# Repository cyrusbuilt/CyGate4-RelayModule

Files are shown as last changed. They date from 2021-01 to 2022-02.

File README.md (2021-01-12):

# CyGate4-RelayModule

Add-on relay module for CyGate4

## Synopsis

This is a relay add-on module for [CyGate4](https://github.com/cyrusbuilt/CyGate4).  It provides 5 addressable relays capable of switching up to 15A @ 125VAC.  This module connects to CyGate4 using the I2C (aka 2-wire) bus. It can be powered from CyGate4 itself, or from a separate 5VDC supply. Support for this module is built-in to the CyGate4 firmware. Since this relay module is based on the MCP23017, it uses a 7bit address scheme where the first 4 bits are already set and the last 3 bits are configurable via jumpers on J1 - J3. The jumpers *MUST* be set and cannot be left off.

For example, the jumper must connect the center pin and either plus (+) or or minus (-) pins. Positive (high) represents a binary 1 and negative (low) represents a binary 0.  You can have a maximum of 7 relay modules (or any other MCP23017-based devices for that matter) connected to CyGate4 at any given time. Be sure to configure that address so as not to conflict with any other devices. NOTE: Address 0 (0x20) is reserved by CyGate4 itself (all jumpers set to center and minus) and cannot be used by any other devices.

As long as the address is configured properly, the device will be auto-detected during CyGate4's boot cycle and initialized. Once initialized, the relays can be configured via CyGate4's config file or via configure/control messages sent to CyGate4 via MQTT.

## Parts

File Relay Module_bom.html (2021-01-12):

Label | Part Type | Properties
C1 | Ceramic Capacitor | voltage 6.3V; capacitance 100nF; package 100 mil [THT, multilayer]
C2 | Ceramic Capacitor | voltage 6.3V; capacitance 100nF; package 100 mil [THT, multilayer]
D1 | Rectifier Diode | type Rectifier; package 300 mil [THT]; part # 1N4001
IC1 | MCP23017 I2C I/O Expander | variant PDIP
IC2 | ULN2803A | variant ULN2803A; package THT
J1 | Generic male header - 3 pins | pin spacing 0.1in (2.54mm); row single; pins 3; form ♂ (male); package THT; hole size 1.0mm,0.508mm
J2 | Generic male header - 3 pins | pin spacing 0.1in (2.54mm); row single; pins 3; form ♂ (male); package THT; hole size 1.0mm,0.508mm
J3 | Generic male header - 3 pins | pin spacing 0.1in (2.54mm); row single; pins 3; form ♂ (male); package THT; hole size 1.0mm,0.508mm
J4 | Screw terminal - 4 pins | pin spacing 0.137in (3.5mm); pins 4; package THT; hole size 1.0mm,0.508mm
J5 | Screw terminal - 3 pins | pin spacing 0.137in (3.5mm); pins 3; package THT; hole size 1.0mm,0.508mm
J6 | Screw terminal - 3 pins | pin spacing 0.137in (3.5mm); pins 3; package THT; hole size 1.0mm,0.508mm
J7 | Screw terminal - 3 pins | pin spacing 0.137in (3.5mm); pins 3; package THT; hole size 1.0mm,0.508mm
J8 | Screw terminal - 3 pins | pin spacing 0.137in (3.5mm); pins 3; package THT; hole size 1.0mm,0.508mm
J9 | Screw terminal - 3 pins | pin spacing 0.137in (3.5mm); pins 3; package THT; hole size 1.0mm,0.508mm
LED1 | Green (565nm) LED | leg yes; package 5 mm [THT]; color Green (565nm)
LED2 | Green (570nm) LED | leg yes; package 3 mm [THT]; color Green (570nm)
LED3 | Green (570nm) LED | leg yes; package 3 mm [THT]; color Green (570nm)
LED4 | Green (570nm) LED | leg yes; package 3 mm [THT]; color Green (570nm)
LED5 | Green (570nm) LED | leg yes; package 3 mm [THT]; color Green (570nm)
LED6 | Green (570nm) LED | leg yes; package 3 mm [THT]; color Green (570nm)
Part1 | Schematic Frame | filename Relay Module.fzz; project CyGate4 - Relay Module; descr Relay Module for CyGate4; rev 1.0; sheet 1/1; date 1610463081
R1 | 150Ω Resistor | tolerance ±5%; resistance 150Ω; bands 4; pin spacing 400 mil; package THT
R2 | 4.7kΩ Resistor | tolerance ±5%; resistance 4.7kΩ; bands 4; pin spacing 400 mil; package THT
R3 | 4.7kΩ Resistor | tolerance ±5%; resistance 4.7kΩ; bands 4; pin spacing 400 mil; package THT
R4 | 4.7kΩ Resistor | tolerance ±5%; resistance 4.7kΩ; bands 4; pin spacing 400 mil; package THT
REL1 | RELAY | variant pth4; package relay-jzc
REL2 | RELAY | variant pth4; package relay-jzc
REL3 | RELAY | variant pth4; package relay-jzc
REL4 | RELAY | variant pth4; package relay-jzc
REL5 | RELAY | variant pth4; package relay-jzc
Amount | Part Type | Properties
2 | Ceramic Capacitor | voltage 6.3V; capacitance 100nF; package 100 mil [THT, multilayer]
1 | Rectifier Diode | type Rectifier; package 300 mil [THT]; part # 1N4001
1 | MCP23017 I2C I/O Expander | variant PDIP
1 | ULN2803A | variant ULN2803A; package THT
3 | Generic male header - 3 pins | pin spacing 0.1in (2.54mm); row single; pins 3; form ♂ (male); package THT; hole size 1.0mm,0.508mm
1 | Screw terminal - 4 pins | pin spacing 0.137in (3.5mm); pins 4; package THT; hole size 1.0mm,0.508mm
5 | Screw terminal - 3 pins | pin spacing 0.137in (3.5mm); pins 3; package THT; hole size 1.0mm,0.508mm
1 | Green (565nm) LED | leg yes; package 5 mm [THT]; color Green (565nm)
5 | Green (570nm) LED | leg yes; package 3 mm [THT]; color Green (570nm)
1 | Schematic Frame | filename Relay Module.fzz; project CyGate4 - Relay Module; descr Relay Module for CyGate4; rev 1.0; sheet 1/1; date 1610463081
1 | 150Ω Resistor | tolerance ±5%; resistance 150Ω; bands 4; pin spacing 400 mil; package THT
3 | 4.7kΩ Resistor | tolerance ±5%; resistance 4.7kΩ; bands 4; pin spacing 400 mil; package THT
5 | RELAY | variant pth4; package relay-jzc

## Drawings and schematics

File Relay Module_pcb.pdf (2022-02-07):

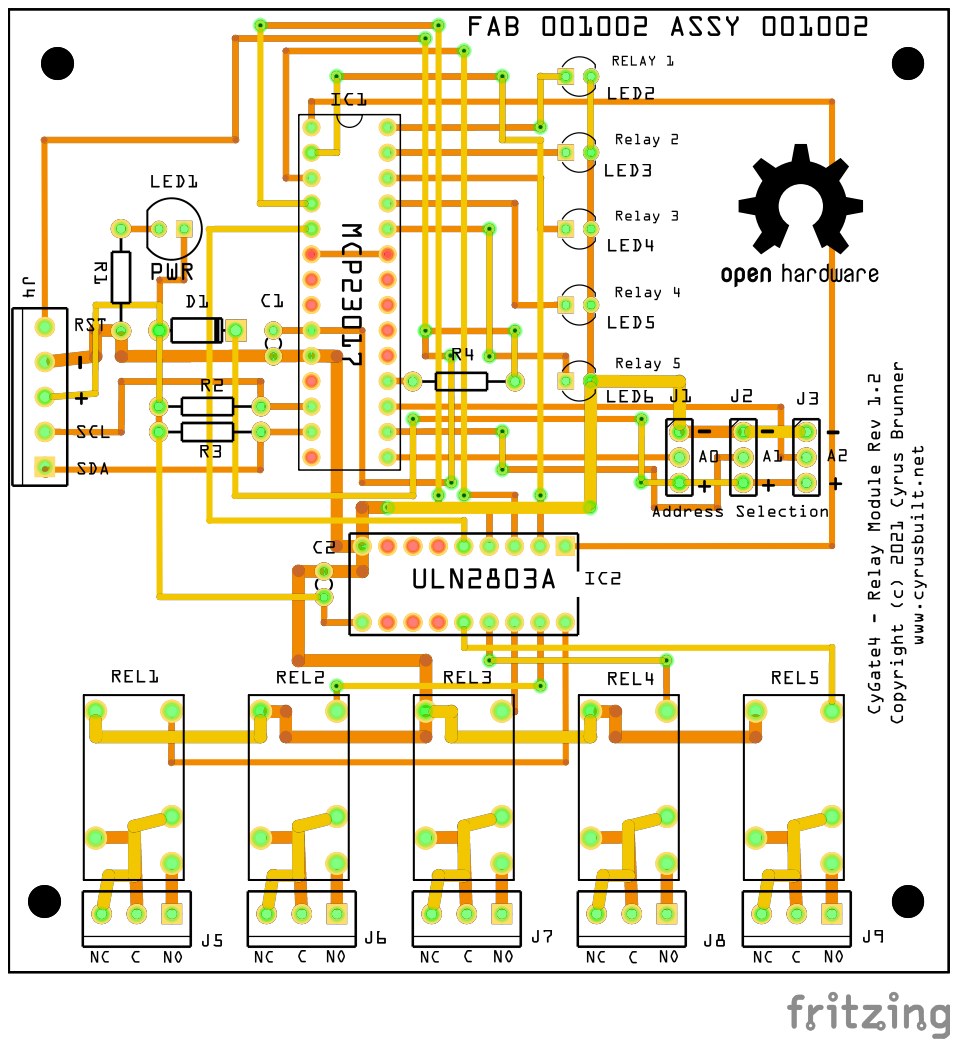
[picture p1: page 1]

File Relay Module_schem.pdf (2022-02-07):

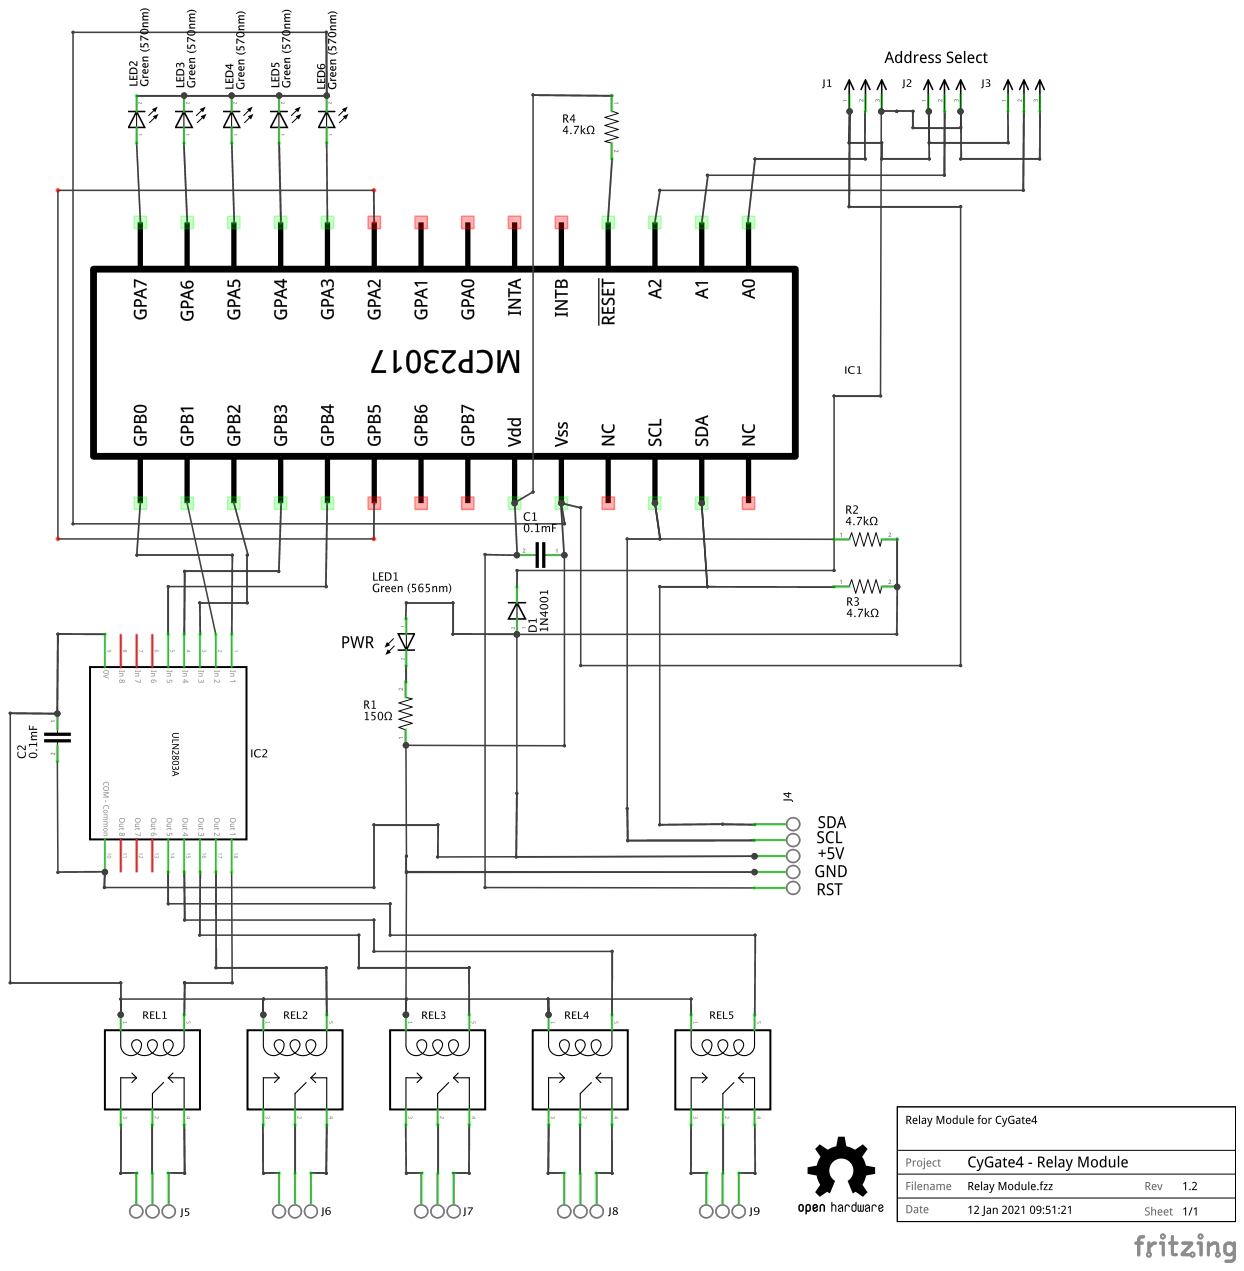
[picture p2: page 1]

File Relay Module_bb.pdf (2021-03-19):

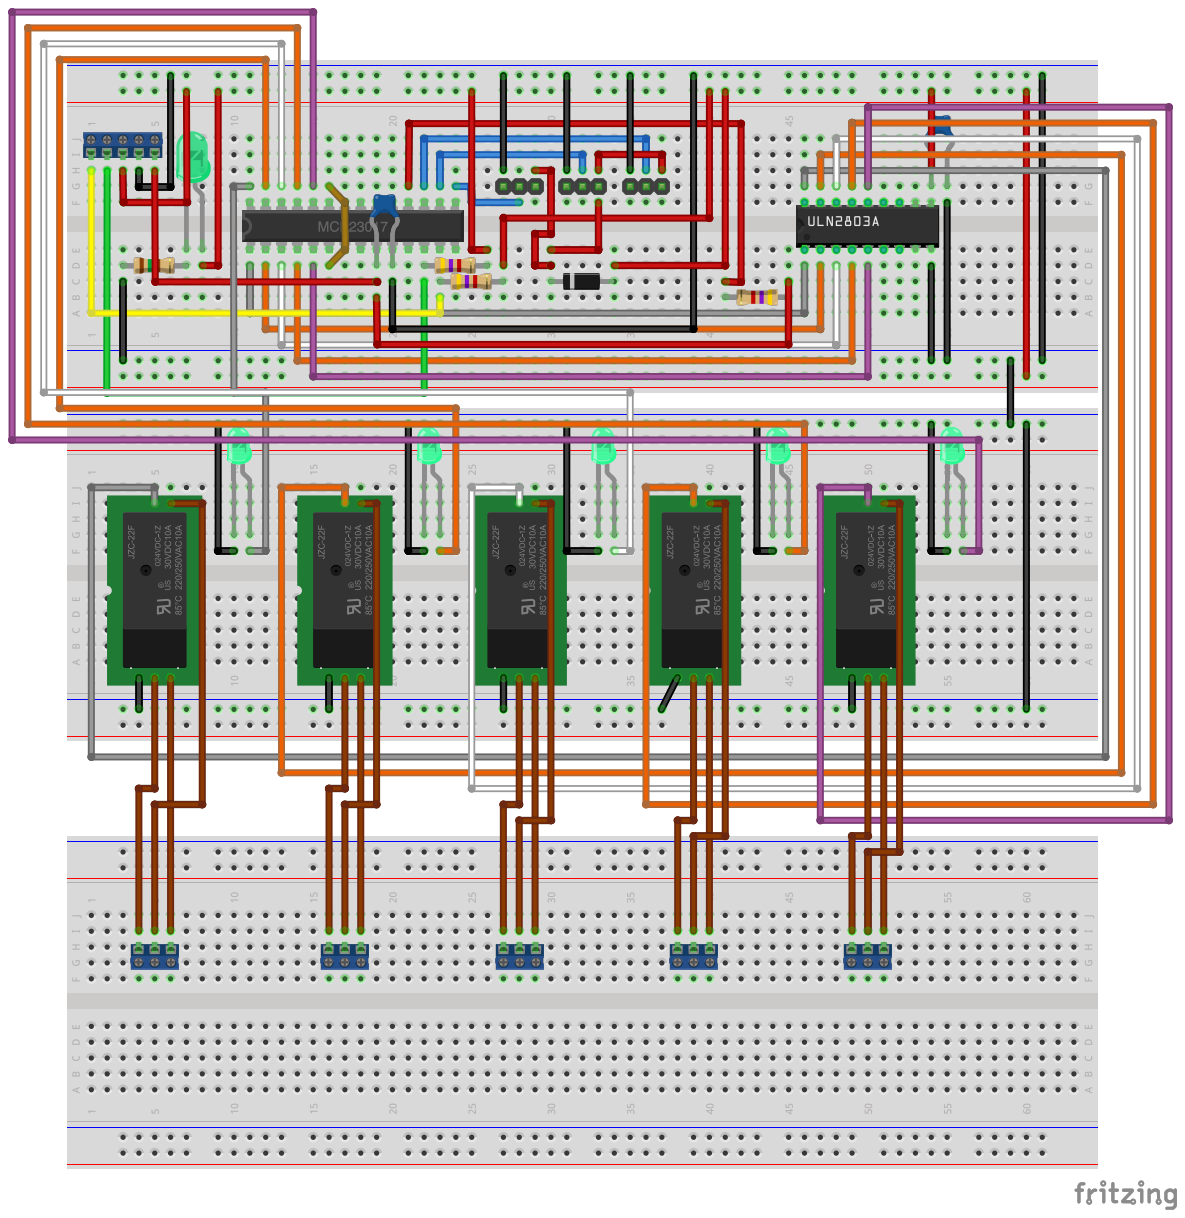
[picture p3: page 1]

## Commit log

2021-01-12 First commit of revision 1.
    [Relay Module.fzz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]
2021-03-19 Fix external reset line
    [Relay Module.fzz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]
2022-02-07 Beef up the ground lines
    [Relay Module.fzz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]
